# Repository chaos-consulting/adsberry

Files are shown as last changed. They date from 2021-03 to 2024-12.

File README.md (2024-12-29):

<p align="center">
  <b>This repo is no longer maintained check out our new repo <a href="https://github.com/sdrmap/docs">https://github.com/sdrmap/docs</a></b>
</p>
<hr></hr>
<p align="center">
  <a href="https://adsb.chaos-consulting.de/" target="_blank">
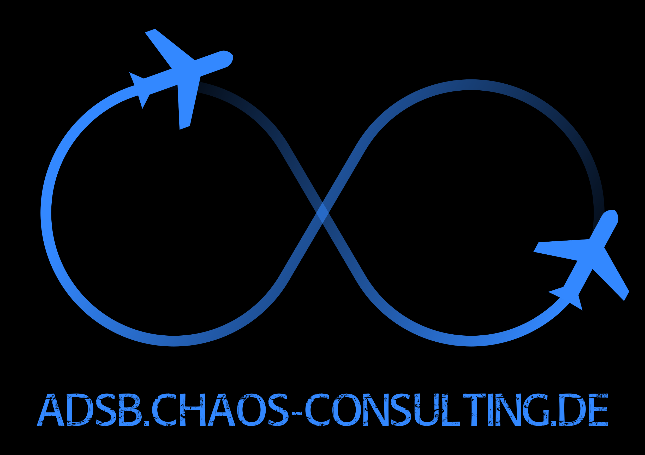
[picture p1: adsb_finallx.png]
https://adsb.chaos-consulting.de/
    <br/>
  </a>
    A hobbyist aircraft and ship tracking network</br>
    <a href="https://adsb.chaos-consulting.de/" target="_blank">https://adsb.chaos-consulting.de/</a>
</p>

## About us
* We are a bunch of hobbyists containing of aviation enthusiasts, ham radio operators, ...
* We are interestet in everyting moving no matter if it is planes, ships, trains or satelites
* We build our own aircraft and ship tracking network

## About our network
* We are noncomercial
* We develop our own application and continue to modify it to our liking
* We are very focused on the feeder stations and we do have a lot of features geared towards them

## Getting started
* Check out our <a href="https://github.com/chaos-consulting/adsberry/wiki">wiki</a> to learn more about building an ADS-B and AIS receiver station
* If you already have a station you can <a href="https://github.com/chaos-consulting/adsberry/wiki/3.-Feeding">start feeding today</a>

<p align="center">
  <a href="https://adsb.chaos-consulting.de/" target="_blank">
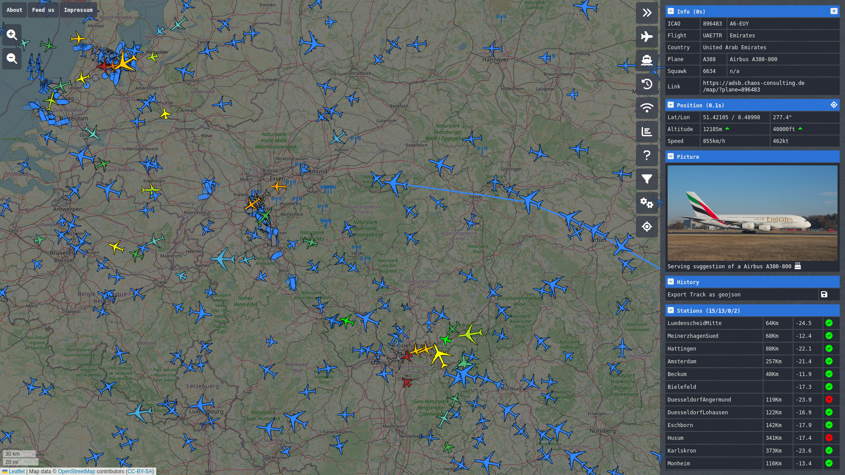
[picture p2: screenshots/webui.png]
    <br/>
  </a>
    <a href="https://adsb.chaos-consulting.de/" target="_blank">https://adsb.chaos-consulting.de/</a>
</p>

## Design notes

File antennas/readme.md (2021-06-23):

# Antennas for ADS-B reception
There are different antennas on the market. Cheap ones as well as expensive ones. Some perform very decently while other models are not working at all.
We like to build our own antennas which should be:
* Cheap to build
* Easy to build
* Small so installation is not an issue
* Long range

## The groundplane
The groundplane is very cheap to make and is a decent performer when build to spec.
### Whats good
* Cheap (roughly 5€ without cable)
* Easy to build
* Good reception

### Whats not so good
* Looks homemade
* Fragile when transported, not so much when installed
* You may need a VNA to tune it to the optimal performance

### Parts needed
* N socket
* 40cm copper wire (1.5mm² or better 2.5mm²)
* 4 M3 bolts and nuts (you may want to add washers)
* SMA -> N RG58 cable to connect it to your bandpass filter and rtl_sdr (length depends on your setup, the shorter the better, we usualy use 1m)

### Tools needed
* Soldering iron + solder
* Wrench for the M3 nuts or pliers
* Wirecutter
* Screwdriver for the M3 screws

### Building the Antenna
Cut 4 about 8cm long copper pieces and create a loop on each end which is big enough for a M3 screw.

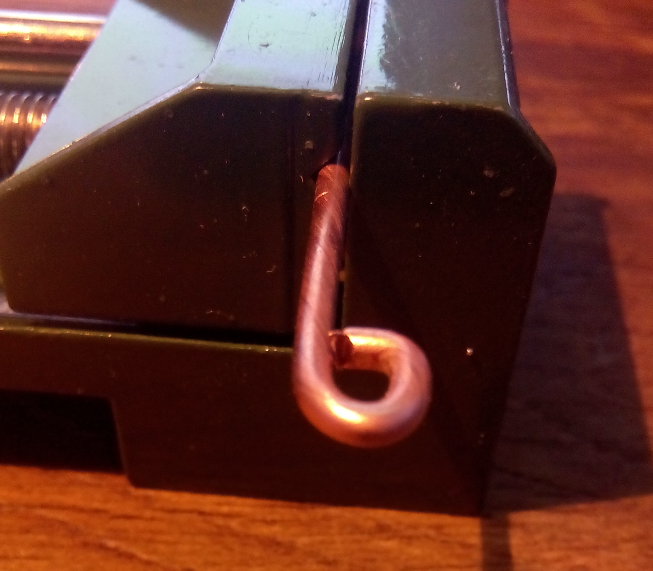
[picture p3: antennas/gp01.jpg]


Solder the loops end for more stability.

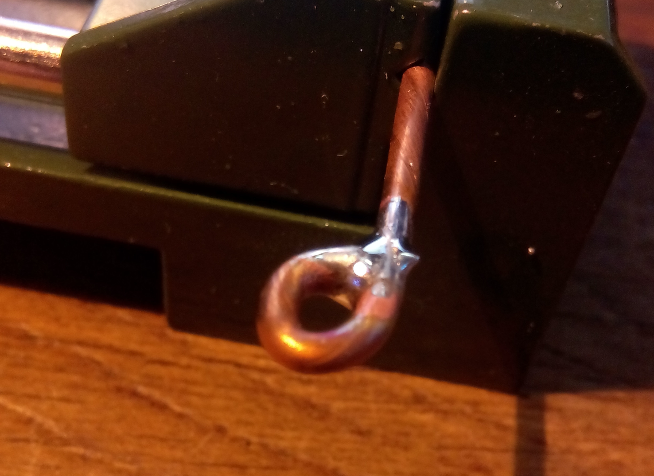
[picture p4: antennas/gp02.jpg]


Cut one 8cm long copper piece

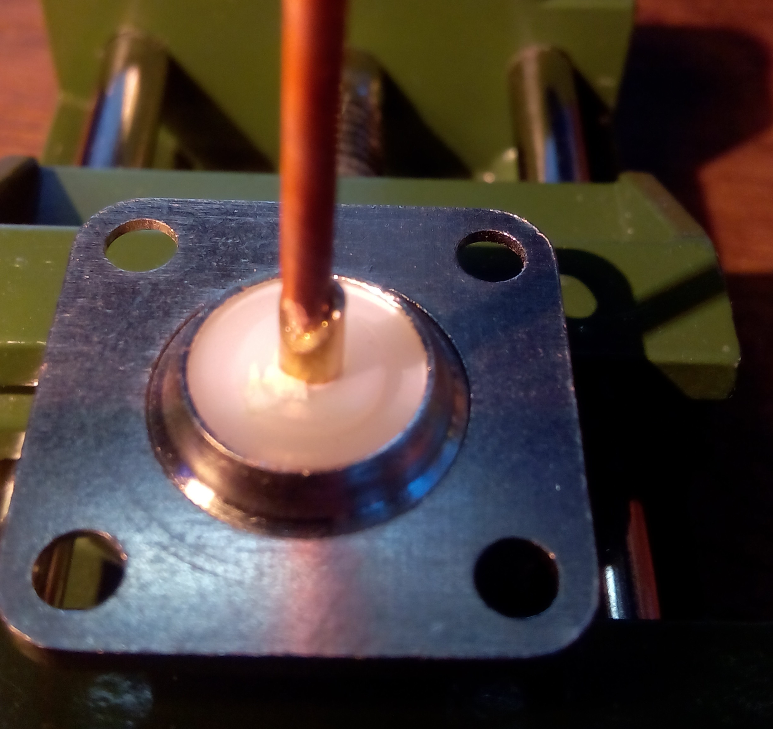
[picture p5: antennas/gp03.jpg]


and solder it into the antenna jacks middle pin.

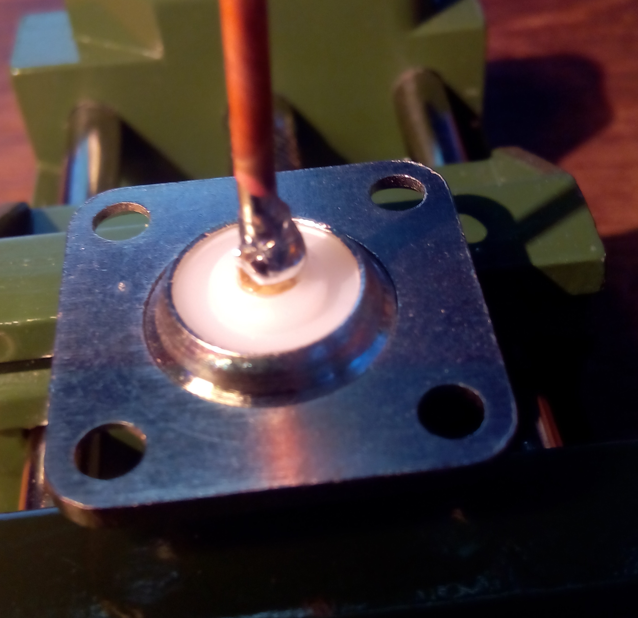
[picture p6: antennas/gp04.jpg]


Screw the four pieces withe the loops to the antenna at an 45° angle

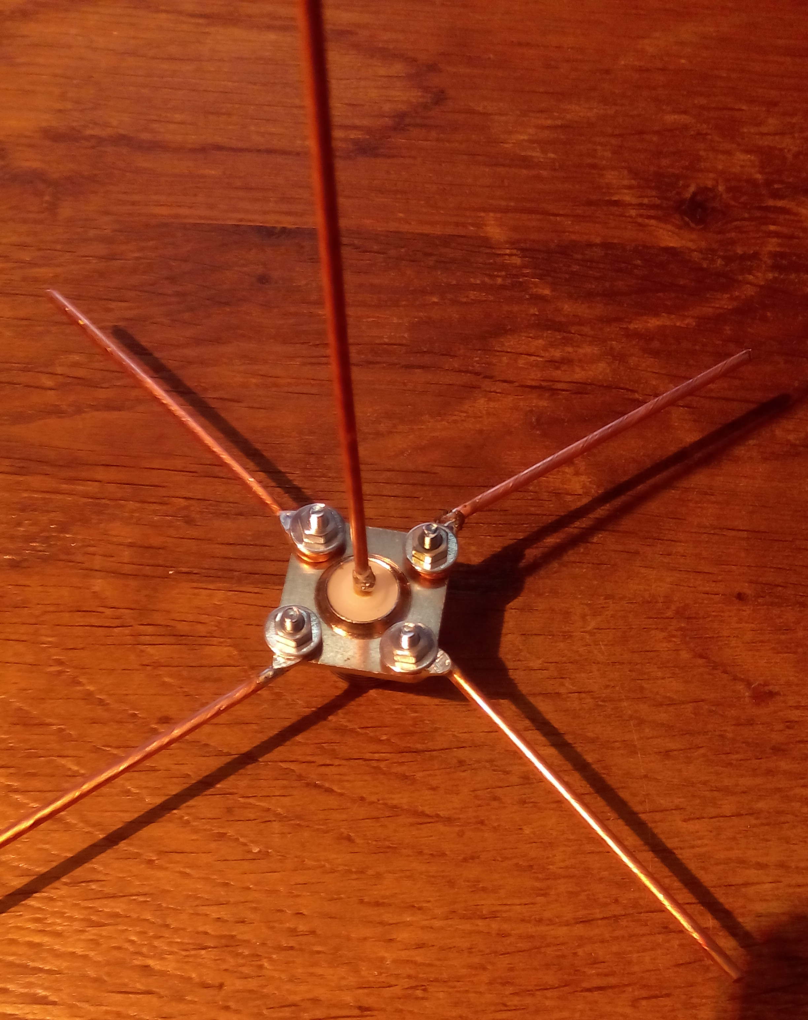
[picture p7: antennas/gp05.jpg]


and bend them down 45°.

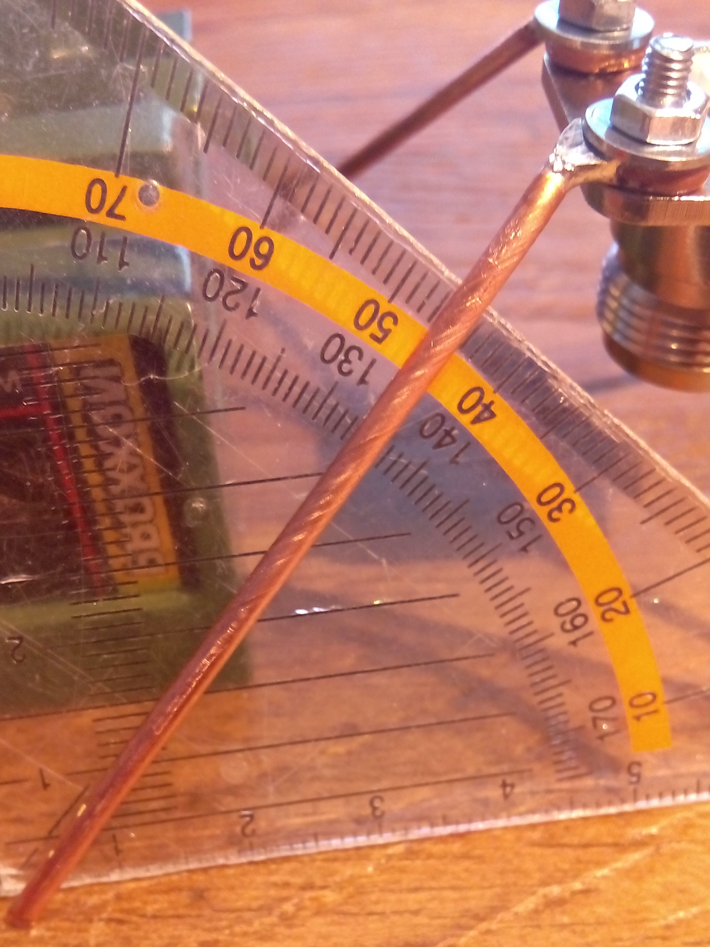
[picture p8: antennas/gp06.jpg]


Connect the antenna and install it in an upright position with clear line of sight.

## The pcb antenna
The pcb antenna is a readily available pcb you find online from China. We build an enclosure to make it waterproof and add mounting brackets.

### Whats good
* No soldering required
* Already tuned to frequency
* Very robust (good for traveling or harsh conditions)
* Looks quite professional
* Excellent performance

### Whats not so good
* A bit more expensive than the groundplane (roughly 20€ without cable)
* If you do not want to drill a big hole for the SMA connector in the bottom you need to crimp your own sma cable after passing it trough the endcap

### Parts needed
* PCB Antenna (search for ADS-B 1090MHz ANT V1.0)
* 30cm of 25mm diameter plastic tube (cable installation tube works great and is cheap)
* 13.8cm of 16mm diameter plastic tube (cable installation tube works great and is cheap)
* 2 plastic endcaps for 25mm diameter (chair leg caps work great)
* 2 1/2" or 22mm conduit clamps with m8 mounting thread
* 2 conduit clamps according to your mounting pole
* 2 3cm long m8 threaded rods (you can use threaded rod cut to length or m8 screws from which you cut off the head)
* sma to sma cable as long as you need, the shorter the better (we use rg58 and crimp our connectors after feeding the cable trough the endcap)

### Tools needed
* Screwdriver for tightening down the clamps (often a size 2 pozidriv)
* Hacksaw with metal cutting blade

### Building the antenna
* Cut your 25mm diameter tube to 30cm
* Cut your 16mm diameter tube to 13,8cm
* Drill a hole in the center of one endcap, choose your drillbit size big enough to feed your sma cable through
* Feed cable through endcap and put cap on tube (can use some glue but not needed)
* Pull the cable through the 25mm diameter tube and the 16mm tube
* Screw the sma connector to the antenna
* The smaller tube will sit inside the bigger tube to prevent the pcb antenna from sliding down
* Pull everything carefully into the tube until the pcb sticks out about 1-2mm
* Put the other endcap on top. No hole and no glue here, so you can access the antenna later on for repairs
* Mount the 22mm conduit clamp on the lower end of the tube 2mm from the endcap with the cablefeed
* Mount the second 22mm clamp a bit higher on the tube in the same direction (stay in the area where there is no pcb to avoid interference with the antenna. 5cm clamp to clamp distance is fine)
* Connect each of the other two conduit clamps with a threaded m8 rod with the clamps on the antenna
* Mount the thing on your mounting pole

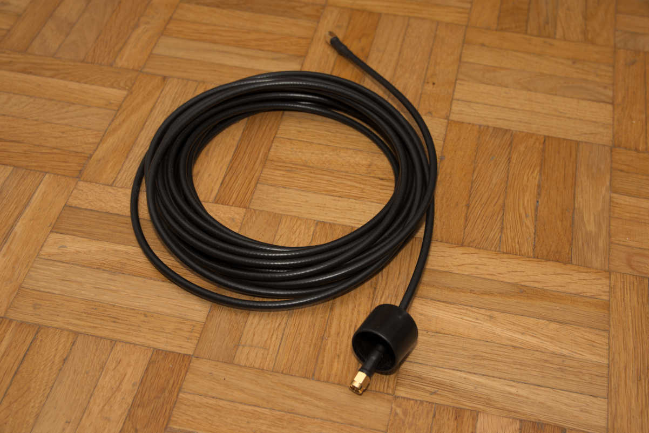
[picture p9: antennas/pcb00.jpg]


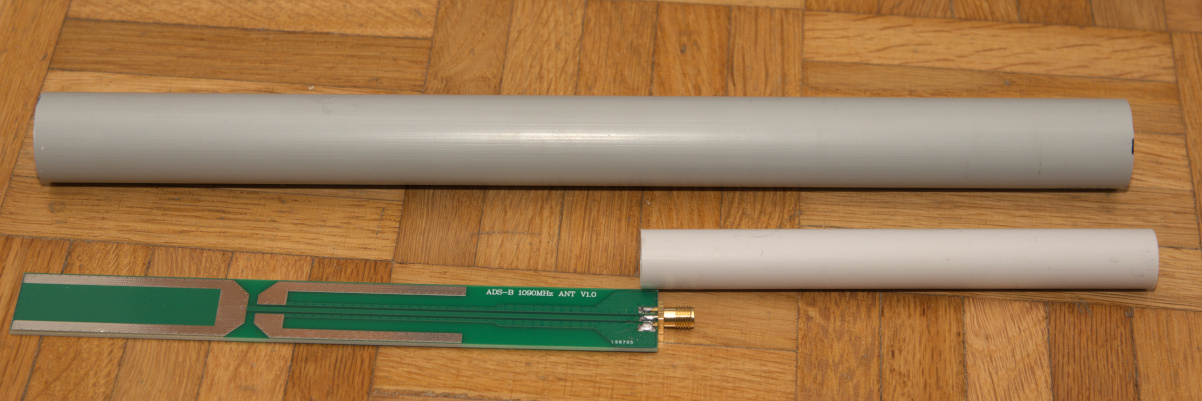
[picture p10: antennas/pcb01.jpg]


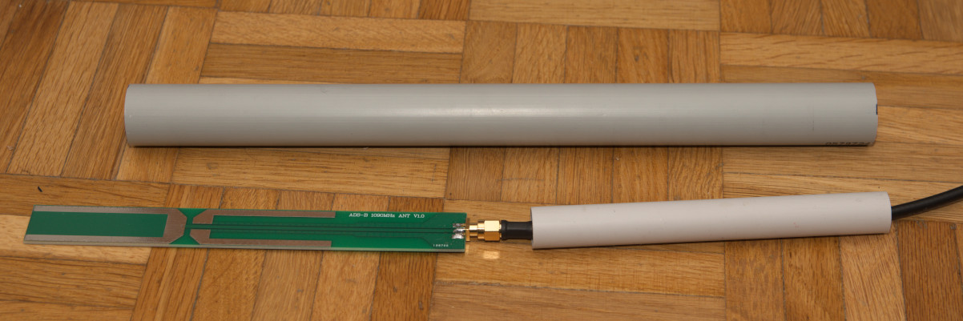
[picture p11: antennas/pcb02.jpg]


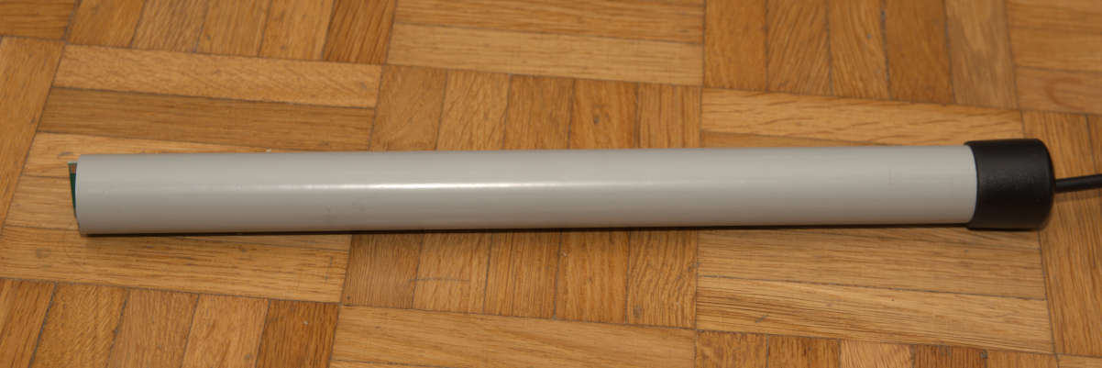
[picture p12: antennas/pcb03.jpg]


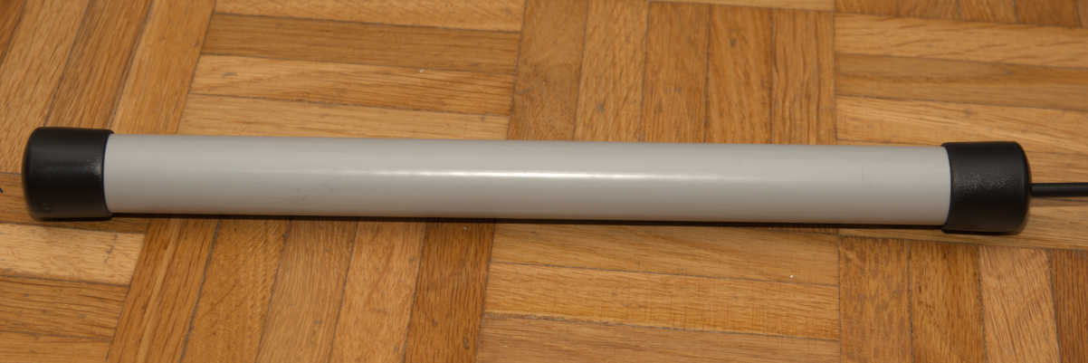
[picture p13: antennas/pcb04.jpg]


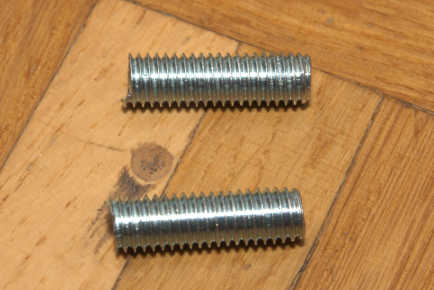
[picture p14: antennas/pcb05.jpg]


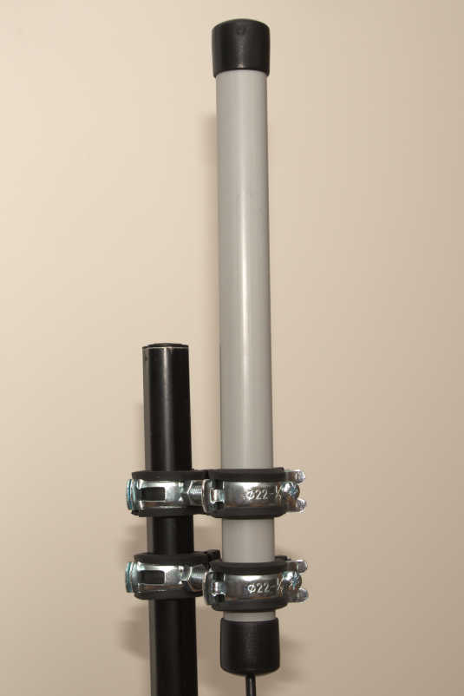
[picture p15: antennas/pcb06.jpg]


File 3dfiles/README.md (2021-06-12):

# Halter und Ständer zum selber ausdrucken

Ein paar Halter und Ständer die man mit seinem 3D-Drucker selber ausdrucken kann.

Mehr Bilder im Unterordner [images](images)

## Antennenmast Halter

Ich habe es in PLA ausgedruckt, es sollte aber besser in einem Filament gedruckt werden, welches UV beständiger ist.
Auf der einen Seite kann man den N-Stecker einklipsen und die andere Seite auf dem Antennenmast (38mm Durchmesser) stecken.

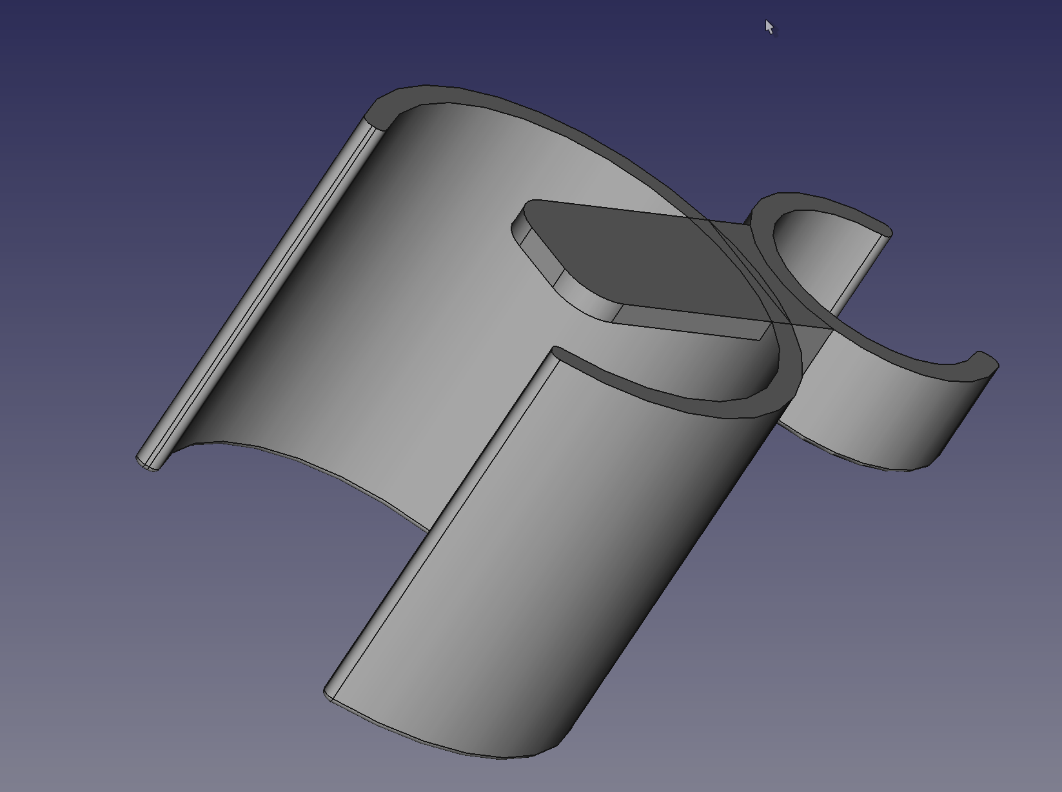
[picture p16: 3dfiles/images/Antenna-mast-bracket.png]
Antenna mast bracket 3D


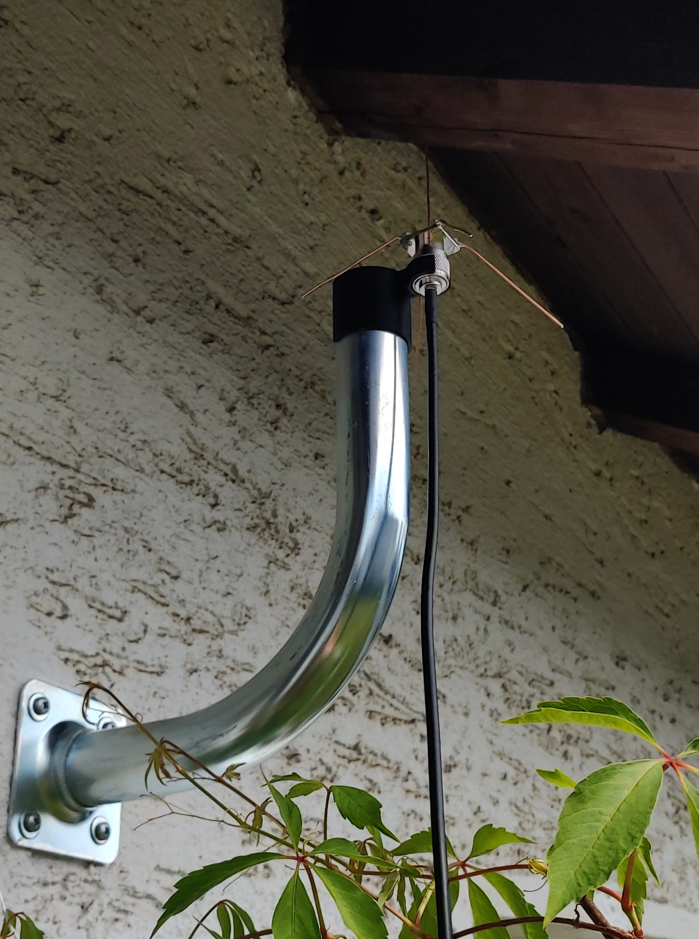
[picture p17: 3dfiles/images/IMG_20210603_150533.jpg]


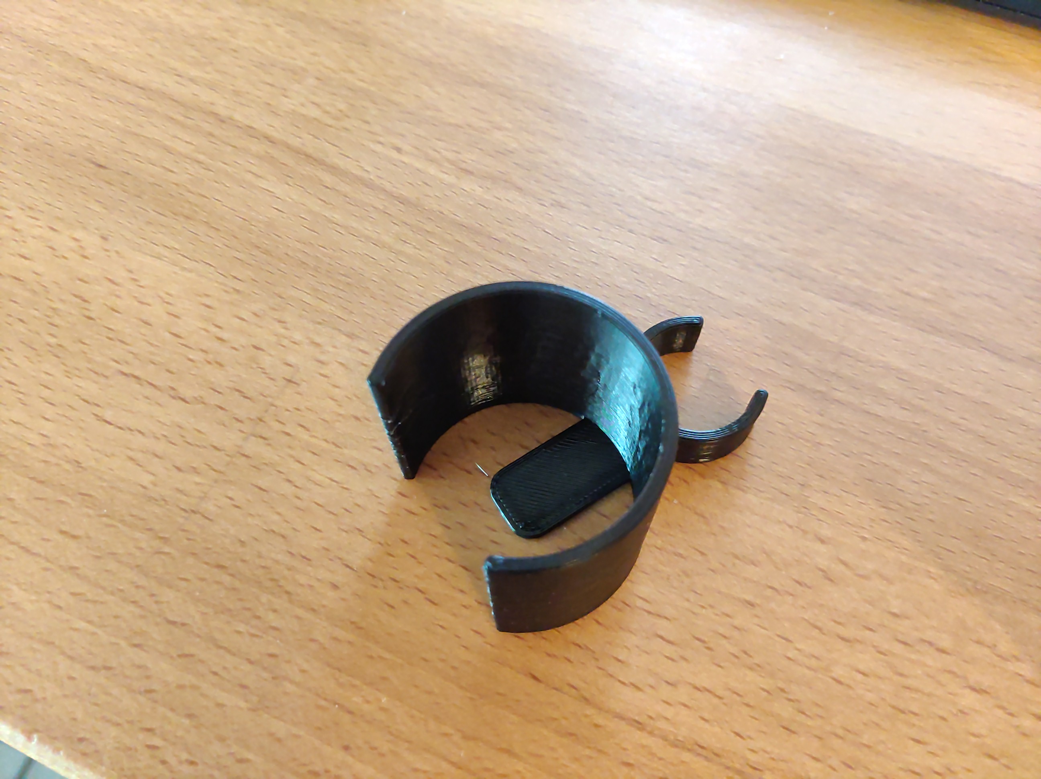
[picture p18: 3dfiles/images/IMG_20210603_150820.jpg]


## Filter Ständer

Ein Ständer um den Filter in einem Gehäuse fest zu montieren. Designt ist er für den FlightAware Bandpass Filter.

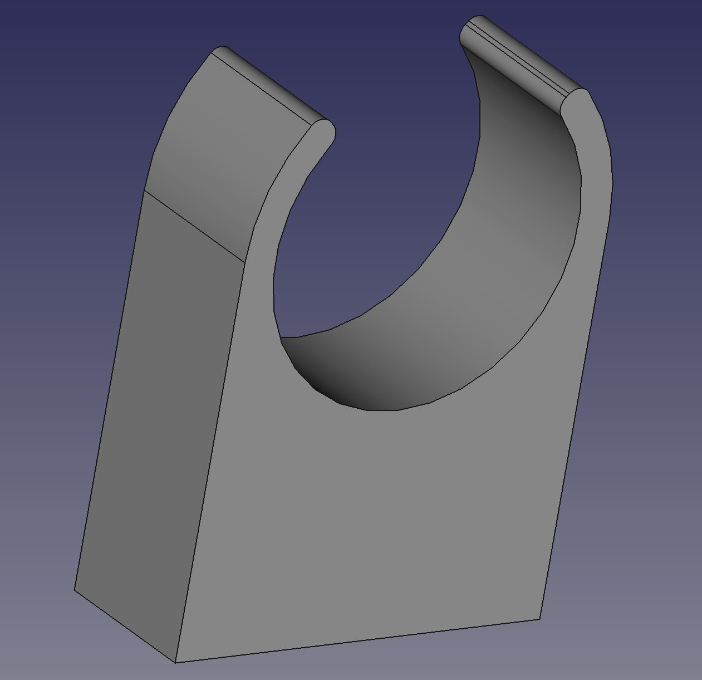
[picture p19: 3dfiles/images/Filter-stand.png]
Filter stand 3D


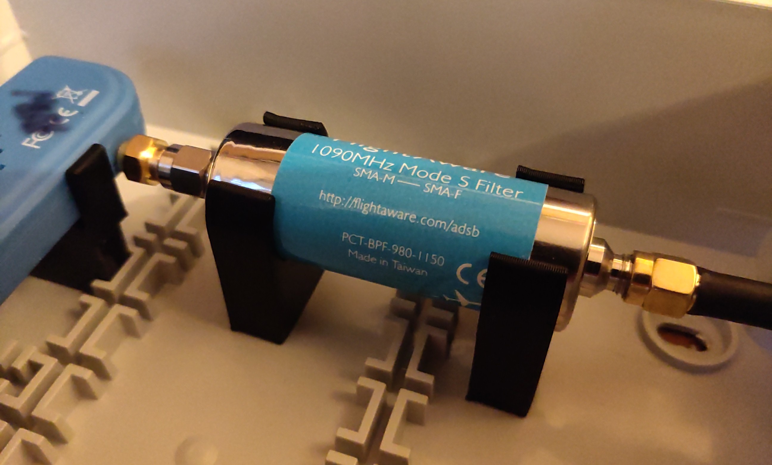
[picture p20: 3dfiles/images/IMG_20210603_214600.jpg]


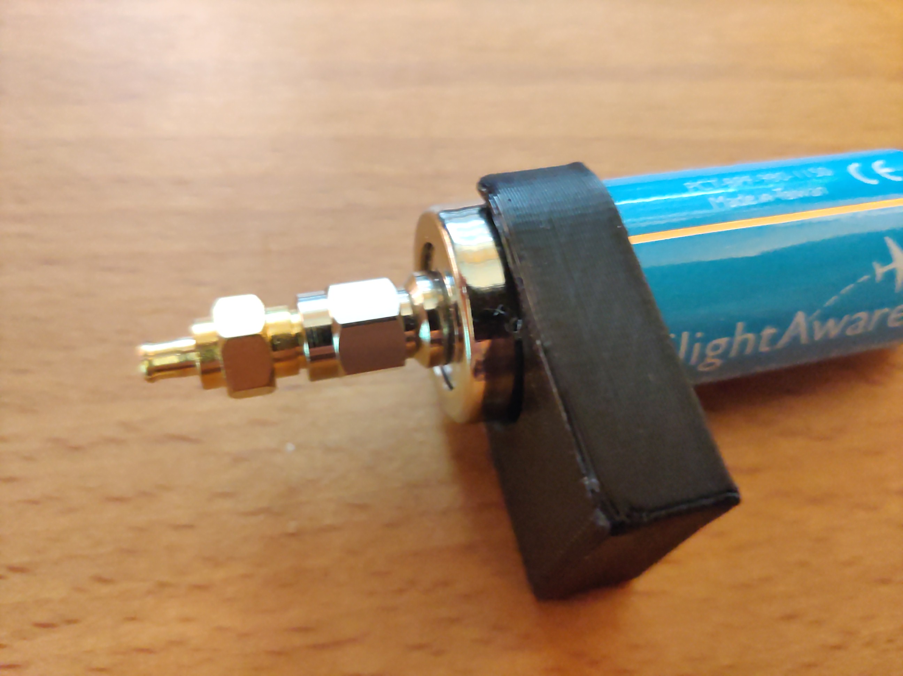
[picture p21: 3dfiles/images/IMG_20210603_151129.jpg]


## USB Stick Ständer

Ein Ständer für einen DVB-T USB-Stick, wenn er maximal 27mm breit und 13mm hoch ist, dann sollte der Ständer passen. Ansonsten kann man in der FreeCAD Projektdatei sich den Halter auch anpassen.

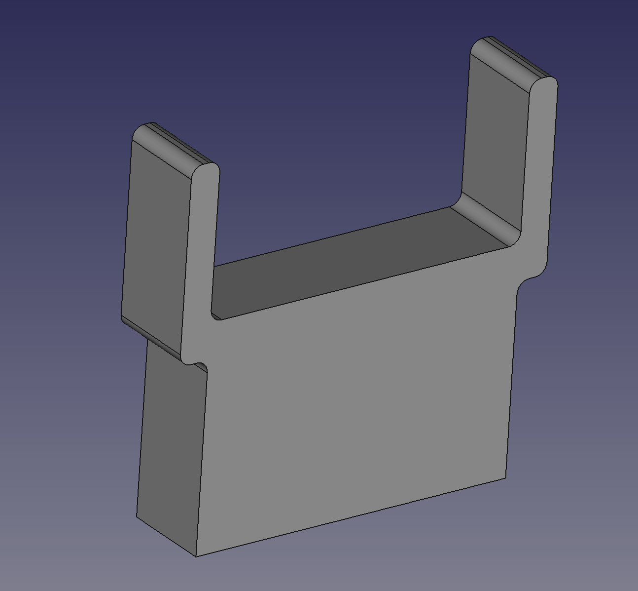
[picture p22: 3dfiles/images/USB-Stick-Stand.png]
USB Stick stand 3D


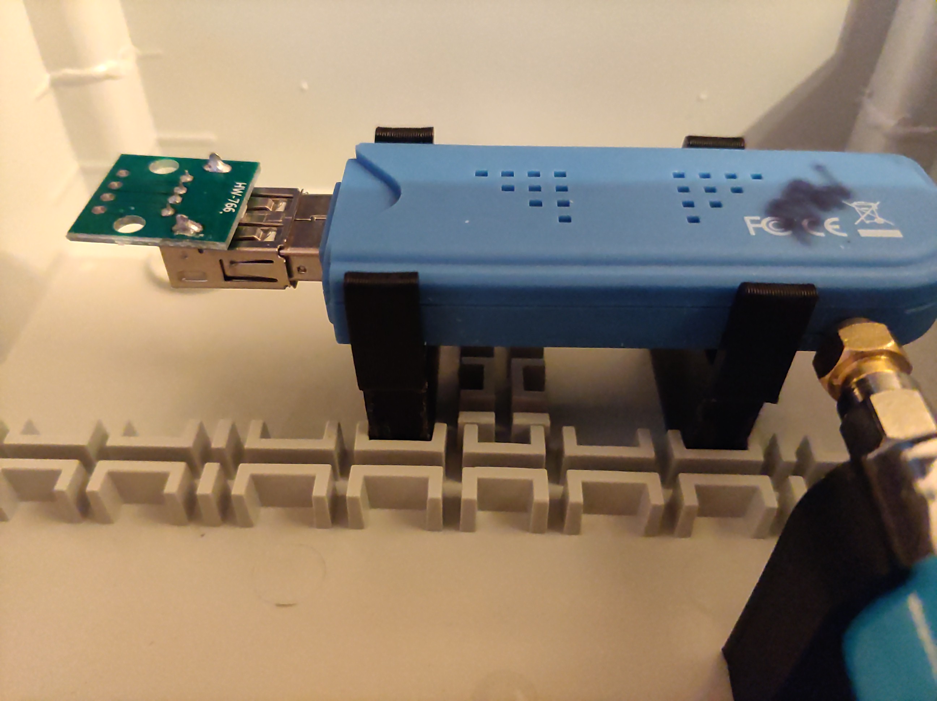
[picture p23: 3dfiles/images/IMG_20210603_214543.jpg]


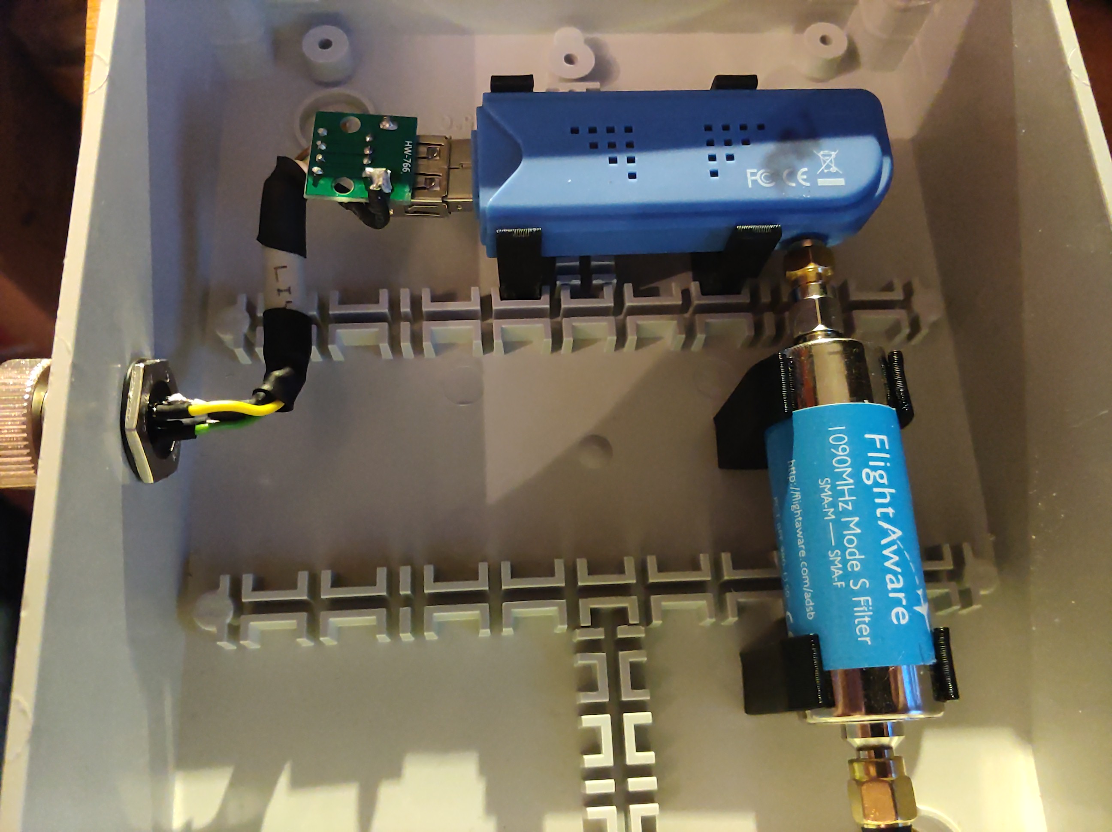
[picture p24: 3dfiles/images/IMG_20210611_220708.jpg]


Mehr Bilder im Unterordner [images](images)

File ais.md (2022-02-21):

# AIS
AIS  stands for Automatic Identification System and is a technology similar to ADS-B but instead for planes it is used on Ships. If you follow the steps in this Chapter of the toutorial you will be able to eceive AIS data and feed it to the big map.

## Prerequisites
* AIS reception: While ADS-B works nearly everywhere in the World AIS is a bit different. Compared to planes all ships are "on flightlevel zero" so to speak, this is the reason why the AIS travels much shorter distances. Under optimal conditions it may travel up to 100km but think more like 20km to begin with. Due to the signals nature it is vital to be near a river or near the sea where AIS equippedships are operating.
* A Raspberry Pi is the preferred computer for this task. It can be the same Raspberry as the ADS-B pi, in fact we run some dual or triple funtion setups on a Raspberry. Du to the limited computing power a Rasperry Pi 1B, 1B+ or Pi Zero will not work in a ADS-B + AIS szenario. For AIS only it will work. A Pi 2B, Pi 3B or Pi 3B+ will work very well. While a Pi 4B is more than you need, you can use it without a problem and it is even recommended if you think of adding more features like a Raspicam, Openwebrx, APRS or the likes on top.
* A Pi with two sdr dongles will use up to 6 watts of peak power so you need a decent power supply. If you are using even more sdrs think of using pwered usb hubs in bethween as your energy consumption can gan go up to 10 watts.
* Keeping your setup cool may be an issue, look for decent cooling of your hardware to ensure stability and longevity of your setup. For Pi 4 wwe highly recommend aluminum enclosures with passive cooling finns.
* As for ADS-B a rtl_sdr dongle is needed. Look for a decent one with R820T or R820T2 Tuner with sma connector and without a bandpass filter.
* A matching antenna needet of course. Build or buy an antenna for 162MHz. The shorter the cable from pi to antenna the better.

## Hardware preperation
You need to change the id / serial number of the rtl dongle you want to use for ais, to distinguish it reliably from the ADS-B dongle. You do not want to mix it up after a reboot, it will result in not working ADS-B and AIS

Plug your AIS dongle in a pc with no other rtl_sdr dongle connected. This can be your Raspberry Pi or every other linux computer wit rtl_sdr installed.

Set the new serial wit
```
rtl_eeprom -s 10000002
```
Now you can access your stick with the number 10000002. Beware that smaller numbers like 2 do not work.

## Software installation
We assume you followed our instructions for an ADS-B Pi with feeding and MLAT and we'll take it from there.

### Install AIScatcher (bullseye)
```
cd ~
wget https://github.com/chaos-consulting/AIS-catcher/releases/download/v0.35/ais-catcher-0.35-1-bullseye_armhf.deb
sudo dpkg -i ais-catcher-0.35-1-bullseye_armhf.deb
```

### Install AIScatcher (buster)
```
cd ~
wget https://github.com/chaos-consulting/AIS-catcher/releases/download/v0.35/ais-catcher-0.35-1-buster_armhf.deb
sudo dpkg -i ais-catcher-0.35-1-buster_armhf.deb
```

### test AIScatcher
```
$ AIS-catcher -d 10000002
Device selected: Realtek, RTL2838UHIDIR, SN: 10000002
Found Rafael Micro R820T tuner
[R82XX] PLL not locked!
Allocating 15 zero-copy buffers
!AIVDM,1,1,,A,339L0eU0010fOHbO76Cp;1ti0000,0*3B ( MSG: 3, REPEAT: 0, MMSI: 211222710)
!AIVDM,1,1,,A,139fw`P001PfOjNO7:mtur4j0<1I,0*26 ( MSG: 1, REPEAT: 0, MMSI: 211533730)
!AIVDM,1,1,,A,13=r2R000:PfKVlO6rw443Dh0<<C,0*56 ( MSG: 1, REPEAT: 0, MMSI: 215909000)
```
!AIVDM indicates, that you are getting real messages from at least one ship

### Register rtl_ais as a service
To make AIS-catcher start with your Pi we register it as a systemd service like this
```
sudo systemctl start ais-catcher@10000002.service
sudo systemctl enable ais-catcher@10000002.service
```

### Install gpsd
GPSd will convert the AIVDM messages into human readable messages.
```
sudo apt install gpsd gpsd-clients
sudo systemctl start gpsd
sudo systemctl enable gpsd
```

Edit the gpsd config in /etc/default/gpsd:
```
GPSD_OPTIONS="udp://127.0.0.1:10110"
```

### Installing the feeder
To send the data to the online map you need to install a little script to feed the data.
```
sudo mkdir -p /opt/ais
sudo wget -O /opt/ais/ais.sh https://raw.githubusercontent.com/chaos-consulting/adsberry/master/scripts/ais.sh
sudo chmod +x /opt/ais/ais.sh
```
Do not forget to edit username and password in /opt/ais/ais.sh
```
sudo nano /opt/ais/ais.sh
```
### Register ais feeder as a service
To make ais feeder start with your Pi we register it as a systemd service like so
```
sudo wget -O /etc/systemd/system/ais.service https://raw.githubusercontent.com/chaos-consulting/adsberry/master/scripts/ais.service
sudo systemctl daemon-reload
sudo systemctl start ais.service
sudo systemctl enable ais.service
```
Thats it!

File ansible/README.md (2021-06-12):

# ADS-B ansible Role

Ansible Playbooks für das installieren von ADS-B auf einem Pi

## Vorbereitungen

### Linux Ubuntu

Ansible per PPA hinzufügen

```bash
sudo add-apt-repository ppa:ansible/ansible
sudo apt update
```

Ansible nun installieren mit `sudo apt install ansible`

## Aufruf

Passe deine Konfiguation in der [hosts.yaml](hosts.yaml) an.

Hinweis: *-K* bewirkt, dass nach dem Passwort vom Benutzer pi gefragt wird um die Befehle mit sudo Rechten auszuführen.

Um das Playbook auszuführen führe folgenden Befehl aus:

```bash
ansible-playbook -i hosts.yaml playbook_adsb.yaml -e 'ansible_python_interpreter=/usr/bin/python3' -K

```

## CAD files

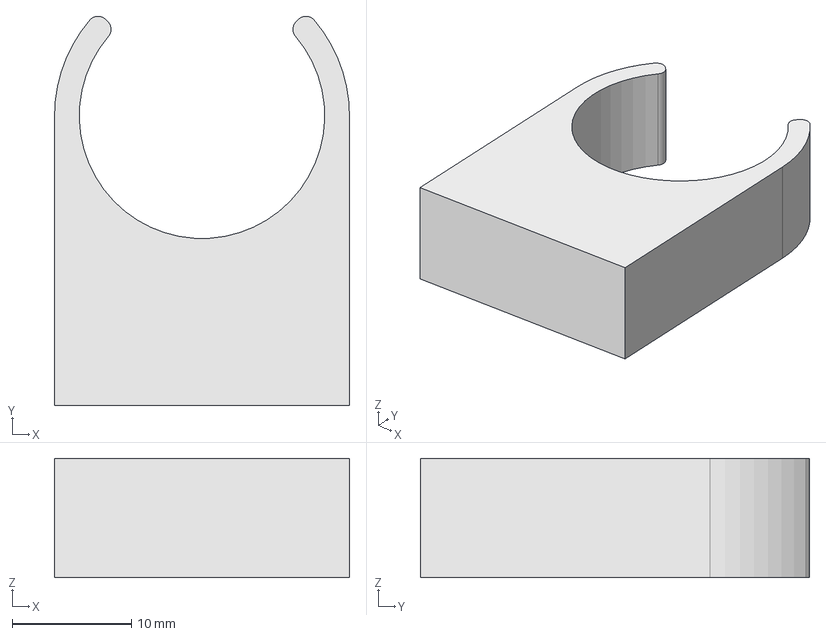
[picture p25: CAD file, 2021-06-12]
3dfiles/files/Filter-stand.FCStd
24.7 x 32.6 x 10.0 mm

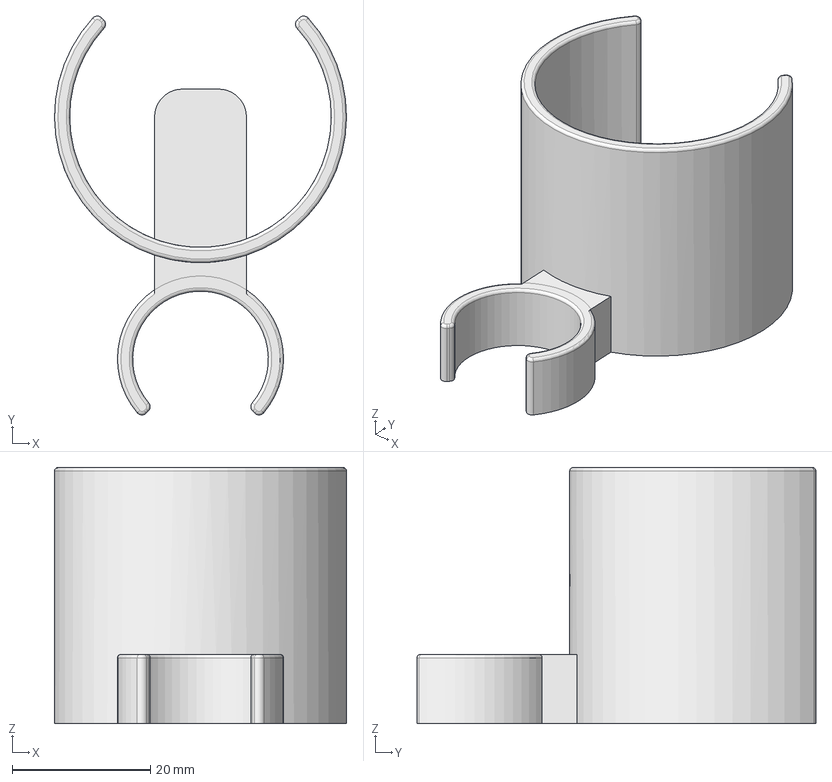
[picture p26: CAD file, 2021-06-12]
3dfiles/files/Antenna-mast-bracket.FCStd
42.2 x 57.6 x 37.0 mm

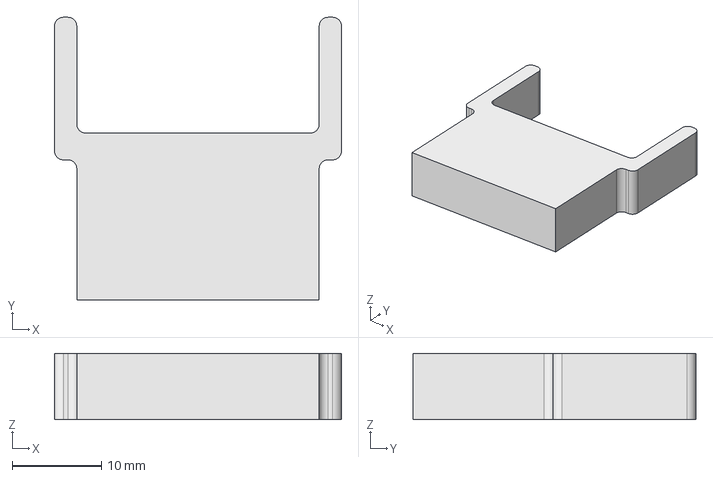
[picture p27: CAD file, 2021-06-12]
3dfiles/files/USB-Stick-Stand.FCStd
32.2 x 31.7 x 7.45 mm

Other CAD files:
3dfiles/files/Antenna-mast-bracket.stl
3dfiles/files/Filter-stand.stl
3dfiles/files/USB-Stick-Stand.stl

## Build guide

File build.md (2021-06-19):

# Bauanleitung - How to Build an ADS-Berry Pi
## Parts List
* Raspberry Pi B, B+ (versions 2 and 3 do work, but are known to instability in our setup because of higher power usage)
* (Micro) SD memory Card with at least 4GB
* Buck Boost Converter
* Passive PoE Splitter
* 30cm USB extension
* Micro USB cord
* rtl-sdr DVB-T dongle with 820T or 820T2 Tuner. Nowerdays it is likely that you get a Fitipower tuner, that ist unfortunately not working for ADS-B
* A Case which is Water Proof
* MCX -> SMA adapter (Only if your sdr dongle is outfitted with a mcx instead of a sma connector
* 1090MHz Bandpassfilter
* M16 wire grommit
* RJ45 grommit
* Antenna for 1090MHz [check our antenna guide](antennas/readme.md)
* Shrinktube
* Construction adhesive
* 24V Passive PoE power supply

## Tools
* Drill for the big holes for the grommits
* Soldering iron + solder
* Pliers
* Wirecutter
* PH2 Screwdriver or long Bit
* Multimeter
* small - screwdriver

## Prepare the box
* Open the box and drill two holes in in one of the small sides, witch enough space around to install both grommits
* This side will be our bottom
* Install the grommits

## Prepare the power
* Cut the barrel connector of the PoE splitter and expose the two wires of the splitter
* Solder the positive one (usually red) to the positive input terminal (+) of the Buck/Boost converter
* Solder the negative one (usually black) to the negative input terminal (-) of the convrter
* Connect the 24V PoE power source via an ethernet cable to the splitter
* Measure the output voltage of the converter with the multimeter set to DC Voltage
* Turn the potentiometer on the converter with a small slotted screwdriver until output ist 5V
* Disconnect the power source
* Cut the micro USB cord to leave about 20cm on the micro connectors side and expose the four wires.
* Cut the data lines D+ and D- usually green and white
* Solder the positive (usually red) and negative (usually black) wires to the positive (+) and negative (-) output terminals of the converter

## Put it all in the box
* Put raspberry in the box
* Connect micro USB for Regualator with 5V in of the Pi
* Connect input of PoE splitter to RJ45 Grommit from the inside
* Connect RJ45 output of the splitter to the Pi
* Connect the rtl-sdr dongle via the usb extension cable to the Pi
* Connect the bandpassfilter via the MCX adapter to the rtl-sdr dongle
* Feed the SMA to N cable with the SMA connector from the outside into the cable grommit in the bottom of the case and connect it to the output of the bandpassfilter
* Tighten up the grommit
* If you like you can secure the parts inside with a bit of construction adhesive but leave enough room to access the memory card slot anytime

## Close the box
* If you inserted your prepared memory card you can secure the boxes lid with the four screws and mount it on a place with clear line of sight for the antenna.
* You can feed data and power via a good quality RJ45 cat6e cable from up to 30m
* Connect the box to the passive PoE output of your injector or switch and connect the injector to your network

## Build the antenna
* [check our antenna guide](antennas/readme.md)

## Next steps
* [As you are done with the hardware side of the build  lets look into the software side](install.md)

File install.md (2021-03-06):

# Installation manual

## Install Raspian Buster Lite
* Download the Image from http://raspberrypi.org
* Be sure to use the lite image, you du not want a fully fledged desktop environment eating up your PIs CPU power
* extract the zip archive
* Write the image to the sd card with dd or look for other ways on the official Raspberry site
* Look for the name of your SD Card via lsbls

```
lsblk
NAME           MAJ:MIN RM   SIZE RO TYPE  MOUNTPOINT
mmcblk0        179:0    0  29,7G  0 disk  
└─mmcblk0p1    179:1    0  29,7G  0 part  /media/user/DingeTM
```
The SD Card ist mmcblk0

```
  sudo dd bs=4M if=~/meinimage.img of=/dev/mmcblk0
```

* On the SD Cards /boot Pratition create a file to activate ssh
```
touch ssh
```

* Put the card into the Pi and boot it up
* Connect via ssh and change the password for security reasons first
* If you connect your PI to a public Network like Freifunk you should use public/private key auth and disable Password auth
* Install software updates and teh needed software packages

```
sudo apt-get update
sudo apt-get dist-upgrade
sudo apt-get autoremove
sudo apt-get install dump1090-mutability
```

* Reboot the Pi and connect via ssh again

## Configure dump1090

```
sudo nano /etc/default/dump1090-mutability
```
* Set your receiver location
* To determine the position do not use your mobile phones GPS functionality it can be quite unreliable, instead use a service like openstreetmap.org where you can right click on the map to show the adrees and coordinates
```
LAT="51.xxxx"
LON="7.yyyyy"
```

## Start dump1090
```
sudo service dump1090-mutability start
```

## Check the output
* Check the number of planes you receive

```
cat /run/dump1090-mutability/aircraft.json|grep -c hex
```
* It is very likely that it wont work, in this case you need to check the log

```
tail -f /var/log/dump1090-mutability.log
```
* If you run into the following error message
```
Please fix the device permissions, e.g. by installing the udev rules file rtl-sdr.rules
```
* You need to create a udev rule file for your particular rtl-sdr dongle
* To do this check the vendor id and product id of your usb dongle
```
lsusb
```
* It will give you a list of all the USB Devices connected similar to the following one
```
Bus 001 Device 004: ID 0bda:2838 Realtek Semiconductor Corp. RTL2838 DVB-T
Bus 001 Device 003: ID 0424:ec00 Standard Microsystems Corp. SMSC9512/9514 Fast Ethernet Adapter
Bus 001 Device 002: ID 0424:9514 Standard Microsystems Corp. SMC9514 Hub
Bus 001 Device 001: ID 1d6b:0002 Linux Foundation 2.0 root hub
```
* The vendor id in this case is 0bda and the product id is 2838
* Now create a rule file
```
sudo nano /etc/udev/rules.d/rtl-sdr.rules
```
* And put the following in it
```
SUBSYSTEM=="usb", ATTRS{idVendor}=="0bda", ATTRS{idProduct}=="2838",  MODE="0666"
```
* Dont forget to change the vendor and product id to the ones matching your sdr dongle
* now reboot and check again if you see a number of Planes and if not check the logfile again

## Feed the data
* [read on in our api doc api.md](api.md)

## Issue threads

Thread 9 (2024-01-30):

No module named 'mlat'

niehauss, 2024-01-30:
mlat stopped working some time ago: log file says:

```
Traceback (most recent call last):
  File "/usr/bin/mlat-client-c2is", line 22, in <module>
    import mlat.client.version
ModuleNotFoundError: No module named 'mlat'
```

```
mlat-client-c2is:
  Installed: 0.3.2-2
  Candidate: 0.3.2-2
  Version table:
 *** 0.3.2-2 500
        500 https://repo.chaos-consulting.de/debian bullseye/main armhf Packages
        100 /var/lib/dpkg/status
```

```

root@adsb-receiver:/home/user# apt policy dump1090-mutability
dump1090-mutability:
  Installed: 1.15~20180310.4a16df3+dfsg-8.1
  Candidate: 1.15~20180310.4a16df3+dfsg-8.1
  Version table:
 *** 1.15~20180310.4a16df3+dfsg-8.1 500
        500 http://raspbian.raspberrypi.org/raspbian bookworm/main armhf Packages
        100 /var/lib/dpkg/status
```

Do you have any idea what might be wrong?

skymaker-c2is, 2024-02-01:
Hi @niehauss,

I guess you've dist-upgraded to bookworm recently. Please make sure to change the raspbian release in /etc/apt/sources.list.d/c2is.list to bookworm, too:

`deb [signed-by=/usr/share/keyrings/c2is.key] https://repo.chaos-consulting.de/debian bullseye main
`

Then, do a sudo apt update and sudo apt upgrade and let me know if it works.

niehauss, 2024-02-01:
> let me know if it works.

Yes, it does.

Thank you very much!

niehauss, 2024-02-02:
Done.

Closed 2024-02-02.

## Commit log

2021-06-12 added 3d files and images
    [Antenna-mast-bracket.FCStd, Antenna-mast-bracket.stl, Filter-stand.FCStd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]
2022-02-22 Create filters
